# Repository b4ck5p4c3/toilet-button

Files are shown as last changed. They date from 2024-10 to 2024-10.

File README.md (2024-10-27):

# toilet-button

B4CKSP4CE button panel in toilet

Written for WCH MCU CH32V003J4M6

## Building

Install WCH [toolchain](https://xpack.github.io/dev-tools/riscv-none-elf-gcc/) to `~/wch/xpack-riscv-none-elf-gcc-12.2.0-1/bin` or change path in `cmake/toolchain-ch32v00x.cmake` file

Run `cmake . && cmake --build .`

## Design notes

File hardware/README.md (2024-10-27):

# hardware

Hardware part of button panel in toilet

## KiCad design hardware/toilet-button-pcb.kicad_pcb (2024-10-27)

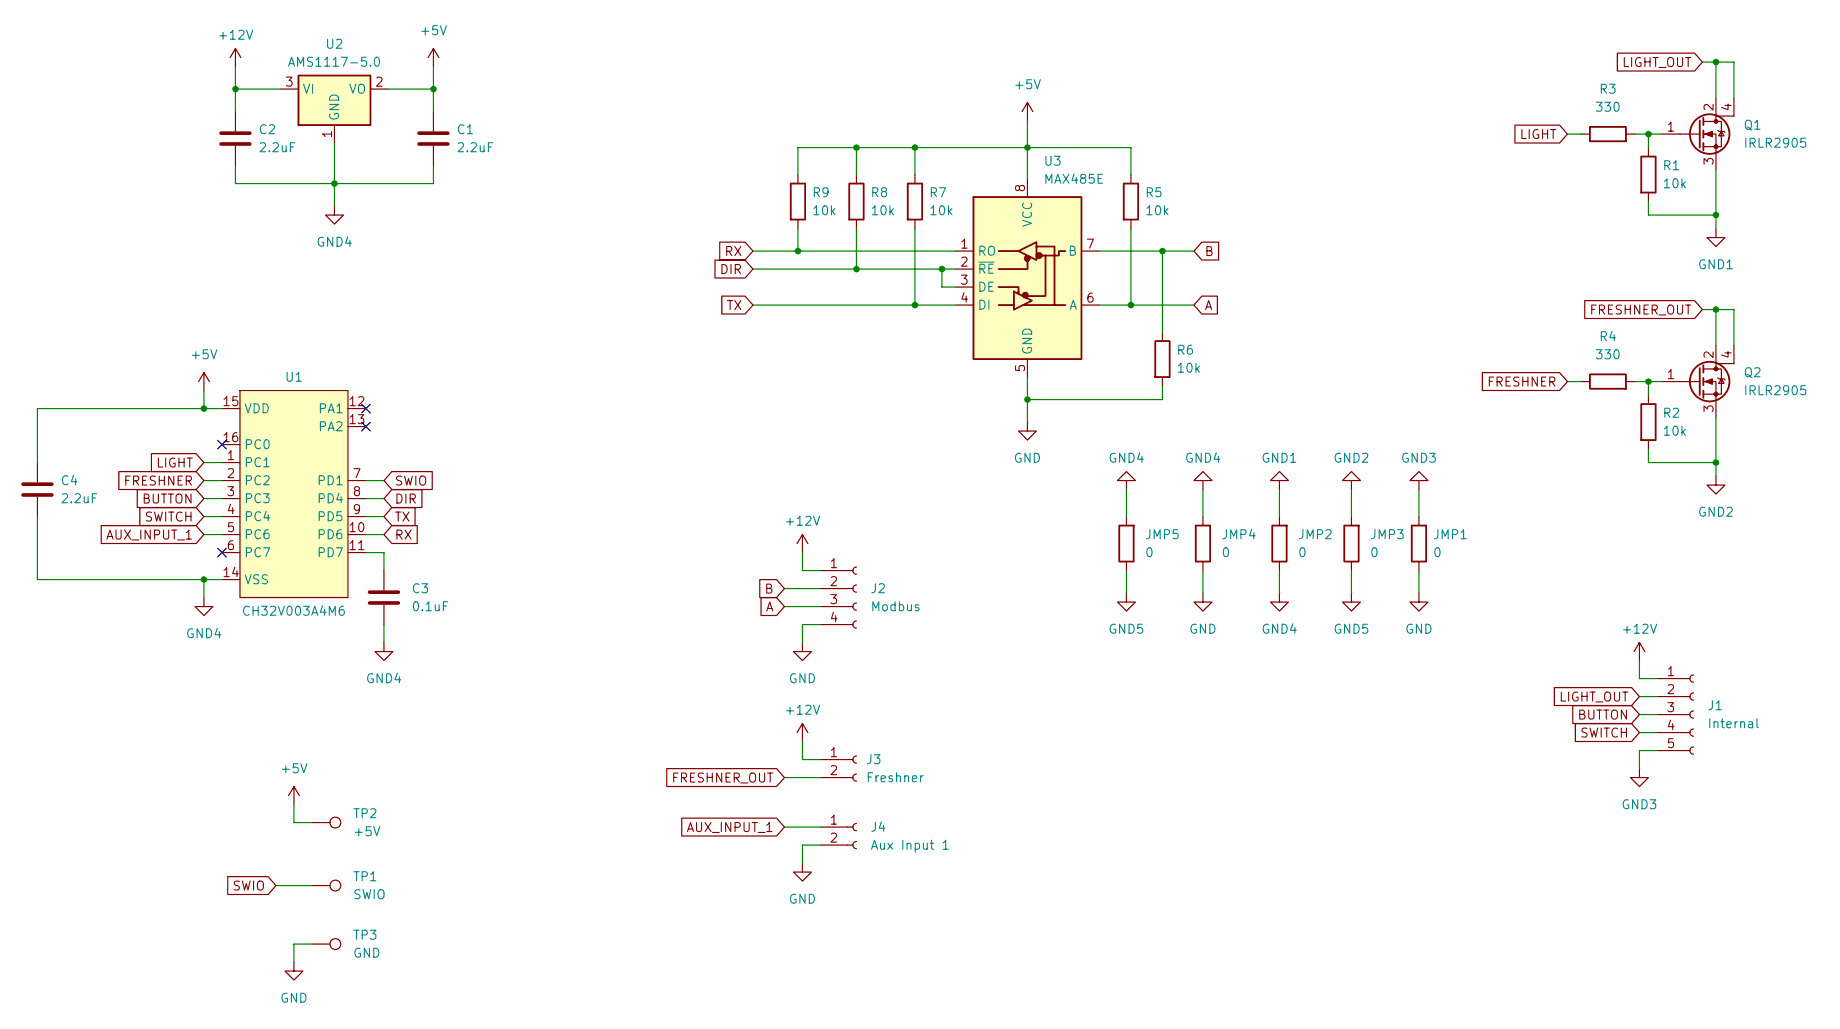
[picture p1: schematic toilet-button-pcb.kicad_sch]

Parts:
C1, C2, C4: 2.2uF; C_1206_3216Metric
C3: 0.1uF; C_1206_3216Metric
J1: Internal; JST_XH_5_SMD
J2: Modbus; Terminal_4_SMD
J3: Freshner; Terminal_2_SMD
J4: Aux Input 1; Terminal_2_SMD
JMP1, JMP2, JMP3, JMP4, JMP5: 0; R_1206_3216Metric
Q1, Q2: IRLR2905; TO-252-3_TabPin4
R1, R2, R5, R6, R7, R8, R9: 10k; R_1206_3216Metric
R3, R4: 330; R_1206_3216Metric
TP1: SWIO; TestPoint_Pad_D2.0mm
TP2: +5V; TestPoint_Pad_D2.0mm
TP3: GND; TestPoint_Pad_D2.0mm
U1: CH32V003A4M6; SOP-16_3.9x9.9mm_P1.27mm
U2: AMS1117-5.0; SOT-223-3_TabPin2
U3: MAX485E; SO-8_3.9x4.9mm_P1.27mm

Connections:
+5V: C1.1, C4.1, R5.1, R7.1, R8.1, R9.1, TP2.1, U1.15 (VDD), U2.2 (VO), U3.8 (VCC)
+12V: C2.1, J1.1, J2.1, J3.1, U2.3 (VI)
A: J2.3, R5.2, U3.6 (A)
AUX_INPUT_1: J4.1, U1.5 (PC6)
B: J2.2, R6.1, U3.7 (B)
BUTTON: J1.3, U1.3 (PC3)
DIR: R8.2, U1.8 (PD4), U3.2 (~RE), U3.3 (DE)
FRESHNER: R4.1, U1.2 (PC2)
FRESHNER_OUT: J3.2, Q2.2 (D), Q2.4 (D)
GND: J2.4, J4.2, JMP1.1, JMP4.1, R6.2, TP3.1, U3.5 (GND)
GND1: JMP2.2, Q1.3 (S), R1.2
GND2: JMP3.2, Q2.3 (S), R2.2
GND3: J1.5, JMP1.2
GND4: C1.2, C2.2, C3.2, C4.2, JMP2.1, JMP4.2, JMP5.2, U1.14 (VSS), U2.1 (GND)
GND5: JMP3.1, JMP5.1
LIGHT: R3.1, U1.1 (PC1)
LIGHT_OUT: J1.2, Q1.2 (D), Q1.4 (D)
unnamed: Q1.1 (G), R1.1, R3.2
unnamed: Q2.1 (G), R2.1, R4.2
unnamed: C3.1, U1.11 (PD7)
RX: R9.2, U1.10 (PD6), U3.1 (RO)
SWIO: TP1.1, U1.7 (PD1)
SWITCH: J1.4, U1.4 (PC4)
TX: R7.2, U1.9 (PD5), U3.4 (DI)

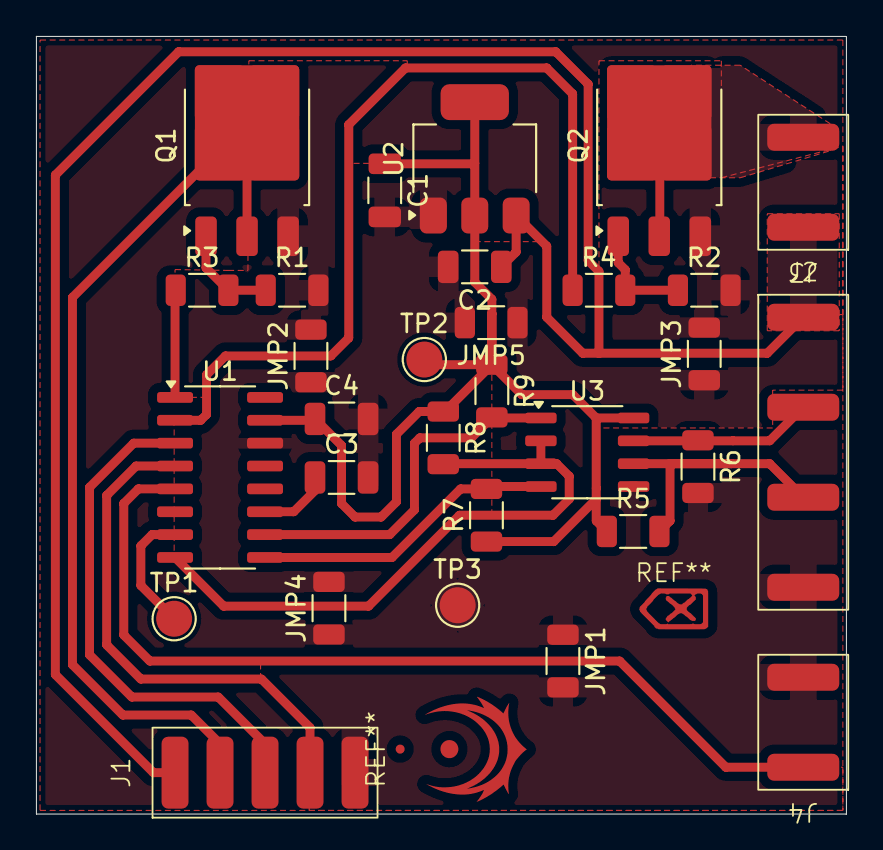
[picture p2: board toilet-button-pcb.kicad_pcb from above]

Board: 2 copper layers, 45.0 x 43.2 mm, 30 parts (0 on the bottom side), 24 nets.

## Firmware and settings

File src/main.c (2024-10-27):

#include <ch32v00x.h>
#include <memory.h>

#include "mcu_config.h"
#include "modbus.h"



void InitGPIOPin(GPIO_TypeDef* gpio, uint16_t pin, GPIOSpeed_TypeDef speed,
                 GPIOMode_TypeDef mode) {
  GPIO_InitTypeDef init = {0};
  init.GPIO_Pin = pin;
  init.GPIO_Speed = speed;
  init.GPIO_Mode = mode;
  GPIO_Init(gpio, &init);
}

void InitGPIO(void) {
  RCC_APB2PeriphClockCmd(RCC_APB2Periph_GPIOC |
                             RCC_APB2Periph_GPIOD | RCC_APB2Periph_AFIO,
                         ENABLE);

  InitGPIOPin(TX_PORT, TX_PIN, GPIO_Speed_50MHz, GPIO_Mode_AF_PP);
  InitGPIOPin(RX_PORT, RX_PIN, GPIO_Speed_50MHz, GPIO_Mode_IN_FLOATING);

  InitGPIOPin(DIR_PORT, DIR_PIN, GPIO_Speed_50MHz, GPIO_Mode_Out_PP);
  GPIO_WriteBit(DIR_PORT, DIR_PIN, Bit_RESET);

  InitGPIOPin(LIGHT_PORT, LIGHT_PIN, GPIO_Speed_50MHz, GPIO_Mode_Out_PP);
  GPIO_WriteBit(LIGHT_PORT, LIGHT_PIN, Bit_RESET);

  InitGPIOPin(FRESHNER_PORT, FRESHNER_PIN, GPIO_Speed_50MHz, GPIO_Mode_Out_PP);
  GPIO_WriteBit(FRESHNER_PORT, FRESHNER_PIN, Bit_RESET);

  InitGPIOPin(BUTTON_PORT, BUTTON_PIN, GPIO_Speed_50MHz, GPIO_Mode_IPU);

  InitGPIOPin(SWITCH_PORT, SWITCH_PIN, GPIO_Speed_50MHz, GPIO_Mode_IPU);

  InitGPIOPin(AUX_INPUT_1_PORT, AUX_INPUT_1_PIN, GPIO_Speed_50MHz, GPIO_Mode_IPU);
}

void InitUART() {
  RCC_APB2PeriphClockCmd(RCC_APB2Periph_USART1, ENABLE);

  USART_InitTypeDef uart;
  uart.USART_BaudRate = MODBUS_SPEED;
  uart.USART_WordLength = USART_WordLength_8b;
  uart.USART_StopBits = USART_StopBits_1;
  uart.USART_Parity = USART_Parity_No;
  uart.USART_Mode = USART_Mode_Rx | USART_Mode_Tx;
  uart.USART_HardwareFlowControl = USART_HardwareFlowControl_None;
  USART_Init(MODBUS_UART, &uart);
  USART_Cmd(MODBUS_UART, ENABLE);
}

void InitButtonInterrupt() {
  EXTI_InitTypeDef exti_init;
  GPIO_EXTILineConfig(BUTTON_PORT_SOURCE, BUTTON_PIN_SOURCE);

  exti_init.EXTI_Line = BUTTON_EXTI_LINE;
  exti_init.EXTI_Mode = EXTI_Mode_Interrupt;
  exti_init.EXTI_Trigger = EXTI_Trigger_Falling;
  exti_init.EXTI_LineCmd = ENABLE;
  EXTI_Init(&exti_init);

  NVIC_InitTypeDef nvic_init;
  nvic_init.NVIC_IRQChannel = EXTI7_0_IRQn;
  nvic_init.NVIC_IRQChannelPreemptionPriority = 1;
  nvic_init.NVIC_IRQChannelSubPriority = 2;
  nvic_init.NVIC_IRQChannelCmd = ENABLE;
  NVIC_Init(&nvic_init);
}

void Init() {
  NVIC_PriorityGroupConfig(NVIC_PriorityGroup_2);
  InitGPIO();
  InitButtonInterrupt();
  InitUART();
}

uint8_t button_was_pressed = 0;

void EXTI7_0_IRQHandler() __attribute__((interrupt("WCH-Interrupt-fast")));

void EXTI7_0_IRQHandler() {
  if (EXTI_GetITStatus(BUTTON_EXTI_LINE) != RESET) {
    button_was_pressed = 1;
    EXTI_ClearITPendingBit(BUTTON_EXTI_LINE);
  }
}

void SetLight(uint8_t set) {
  GPIO_WriteBit(LIGHT_PORT, LIGHT_PIN, set ? Bit_SET : Bit_RESET);
}

void SetFreshner(uint8_t set) {
  GPIO_WriteBit(FRESHNER_PORT, FRESHNER_PIN, set ? Bit_SET : Bit_RESET);
}

#define MAX_COILS 2
#define MAX_INPUTS 3

void SetCoil(uint16_t coil, uint8_t set) {
  switch (coil) {  // NOLINT(hicpp-multiway-paths-covered)
    case 0:
      SetLight(set);
      break;
    case 1:
      SetFreshner(set);
      break;
  }
}

uint8_t GetInput(uint16_t input) {
  switch (input) {  // NOLINT(hicpp-multiway-paths-covered)
    case 0: {
      uint8_t value = button_was_pressed;
      button_was_pressed = 0;
      return value || !GPIO_ReadInputDataBit(BUTTON_PORT, BUTTON_PIN);
    }
    case 1: {
      return !GPIO_ReadInputDataBit(SWITCH_PORT, SWITCH_PIN);
    }
    case 2: {
      return !GPIO_ReadInputDataBit(AUX_INPUT_1_PORT, AUX_INPUT_1_PIN);
    }
  }
  return 0;
}

void SendModbusException(uint8_t function, uint8_t exception_code) {
  uint8_t response[3] = {MODBUS_SLAVE_ID, function | 0x80, exception_code};
  SendModbusPacket(response, sizeof(response));
}

void SendModbusReadDiscreteInputsResponse(uint8_t* data, uint8_t bytes) {
  uint8_t response[1 + 1 + 1 + (MAX_INPUTS + 7) / 8] = {
      MODBUS_SLAVE_ID, MODBUS_PACKET_FUNCTION_CODE_READ_DISCRETE_INPUTS, bytes};
  memcpy(response + 3, data, bytes);
  SendModbusPacket(response, 1 + 1 + 1 + bytes);
}

void SendModbusWriteSingleCoilResponse(uint16_t address, uint16_t value) {
  uint8_t response[6] = {
      MODBUS_SLAVE_ID, MODBUS_PACKET_FUNCTION_CODE_WRITE_SINGLE_COIL,
      address >> 8,    address & 0xFF,
      value >> 8,      value & 0xFF};
  SendModbusPacket(response, sizeof(response));
}

void SendModbusWriteMultipleCoilResponse(uint16_t address, uint16_t number) {
  uint8_t response[6] = {
      MODBUS_SLAVE_ID, MODBUS_PACKET_FUNCTION_CODE_WRITE_MULTIPLE_COILS,
      address >> 8,    address & 0xFF,
      number >> 8,     number & 0xFF};
  SendModbusPacket(response, sizeof(response));
}

void ProcessModbus() {
  ModbusPacket packet;
  enum ModbusReadError error = ReadModbusPacket(&packet);
  switch (error) {
    case MODBUS_READ_ERROR_WRONG_PACKET_SIZE:
    case MODBUS_READ_ERROR_WRONG_CRC:
      return;
    case MODBUS_READ_ERROR_UNSUPPORTED_PACKET:
      if (packet.slave_id == MODBUS_SLAVE_ID) {
        SendModbusException(packet.function,
                            MODBUS_EXCEPTION_CODE_ILLEGAL_FUNCTION);
      }
      return;
    case MODBUS_READ_ERROR_SUCCESS:
      break;
  }

  if (packet.slave_id != MODBUS_SLAVE_ID) {
    return;
  }

  switch (packet.function) {
    case MODBUS_PACKET_FUNCTION_CODE_READ_DISCRETE_INPUTS:
      if (packet.read_discrete_inputs_data.address +
              packet.read_discrete_inputs_data.number >
          MAX_INPUTS) {
        SendModbusException(packet.function,
                            MODBUS_EXCEPTION_CODE_ILLEGAL_DATA_ADDRESS);
        return;
      }
      uint8_t response_data[(MAX_INPUTS + 7) / 8] = {};
      for (uint32_t i = 0; i < packet.read_discrete_inputs_data.number; i++) {
        response_data[i / 8] |=
            GetInput(i + packet.read_discrete_inputs_data.address) << (i % 8);
      }
      SendModbusReadDiscreteInputsResponse(
          response_data, (packet.read_discrete_inputs_data.number + 7) / 8);
      break;
    case MODBUS_PACKET_FUNCTION_CODE_WRITE_SINGLE_COIL:
      if (packet.write_single_coil_data.address >= MAX_COILS) {
        SendModbusException(packet.function,
                            MODBUS_EXCEPTION_CODE_ILLEGAL_DATA_ADDRESS);
        return;
      }
      SetCoil(packet.write_single_coil_data.address,
              packet.write_single_coil_data.value == 0xFF00);
      SendModbusWriteSingleCoilResponse(packet.write_single_coil_data.address,
                                        packet.write_single_coil_data.value);
      break;
    case MODBUS_PACKET_FUNCTION_CODE_WRITE_MULTIPLE_COILS:
      if (packet.write_multiple_coils_data.address +
              packet.write_multiple_coils_data.number >
          MAX_COILS) {
        SendModbusException(packet.function,
                            MODBUS_EXCEPTION_CODE_ILLEGAL_DATA_ADDRESS);
        return;
      }
      if ((packet.write_multiple_coils_data.number + 7) / 8 !=
          packet.write_multiple_coils_data.bytes) {
        SendModbusException(packet.function,
                            MODBUS_EXCEPTION_CODE_ILLEGAL_DATA_ADDRESS);
        return;
      }
      for (uint32_t i = 0; i < packet.write_multiple_coils_data.number; i++) {
        SetCoil(packet.write_multiple_coils_data.address + i,
                (packet.write_multiple_coils_data.data[i / 8] >> (i % 8)) & 1);
      }
      SendModbusWriteMultipleCoilResponse(
          packet.write_multiple_coils_data.address,
          packet.write_multiple_coils_data.number);
      break;
  }
}

int main(void) {
  Init();

#pragma clang diagnostic push
#pragma ide diagnostic ignored "EndlessLoop"
  while (1) {
    ProcessModbus();
  }
#pragma clang diagnostic pop
}

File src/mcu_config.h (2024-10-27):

#ifndef TOILET_BUTTON_MCU_CONFIG_H
#define TOILET_BUTTON_MCU_CONFIG_H

#include <ch32v00x.h>

#define MODBUS_UART USART1
#define MODBUS_SPEED 115200
#define MODBUS_SLAVE_ID 228

#define TX_PORT GPIOD
#define TX_PIN GPIO_Pin_5

#define RX_PORT GPIOD
#define RX_PIN GPIO_Pin_6

#define DIR_PORT GPIOD
#define DIR_PIN GPIO_Pin_4

#define LIGHT_PORT GPIOC
#define LIGHT_PIN GPIO_Pin_1

#define FRESHNER_PORT GPIOC
#define FRESHNER_PIN GPIO_Pin_2

#define BUTTON_PORT GPIOC
#define BUTTON_PIN GPIO_Pin_3
#define BUTTON_PORT_SOURCE GPIO_PortSourceGPIOC
#define BUTTON_PIN_SOURCE GPIO_PinSource3
#define BUTTON_EXTI_LINE EXTI_Line3

#define SWITCH_PORT GPIOC
#define SWITCH_PIN GPIO_Pin_4

#define AUX_INPUT_1_PORT GPIOC
#define AUX_INPUT_1_PIN GPIO_Pin_6

#endif  //TOILET_BUTTON_MCU_CONFIG_H
